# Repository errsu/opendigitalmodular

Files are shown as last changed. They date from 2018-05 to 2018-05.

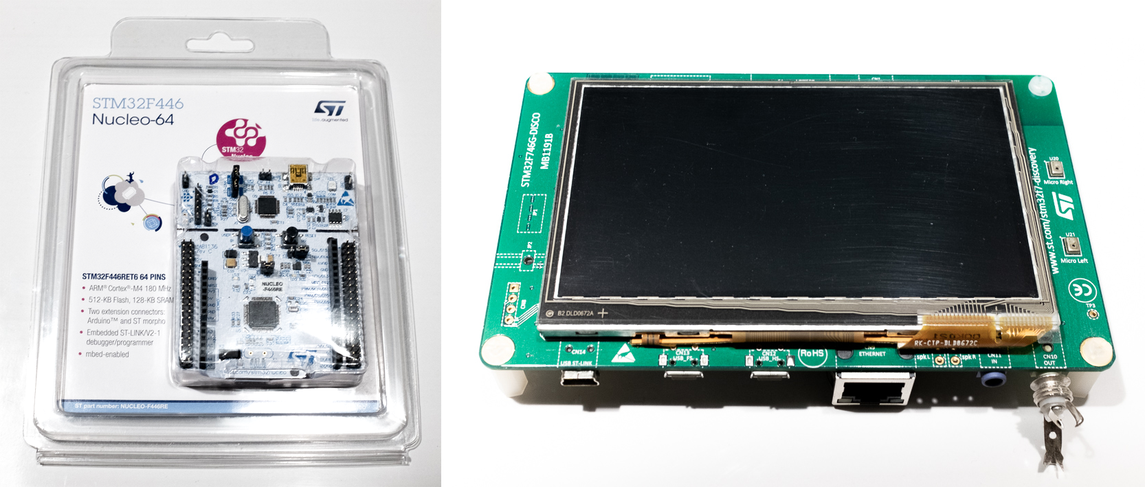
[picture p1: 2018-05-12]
documentation/images/stm32f_evaluation_boards.png

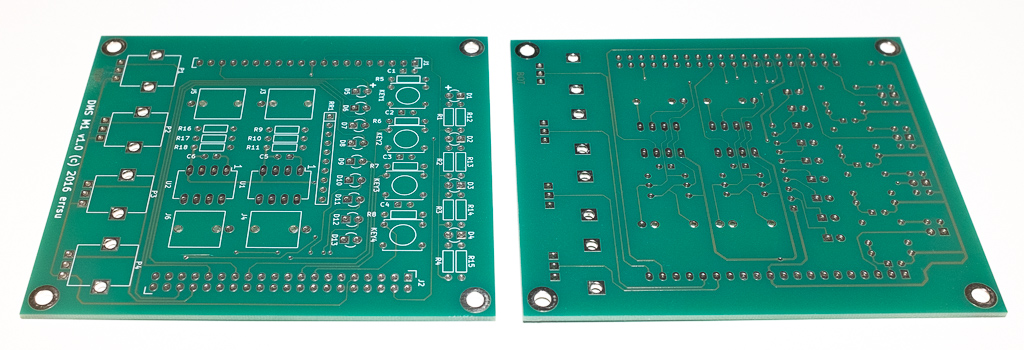
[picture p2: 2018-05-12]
documentation/images/odm_m1_pcb.png

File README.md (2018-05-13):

Open Digital Modular (ODM): Proposal for a Synthesizer Architecture
===================================================================

## What is it?

ODM is an architectural idea that is to be turned into a specification and
a prototype implementation. All this is work in progress. The details can
be found in the [ODM specification document](documentation/ODMSpecification.asc).

## License

See the [licenses page](LICENSES.asc) for details.

## Questions and comments

The main goal of making this public is to get in contact with people for review,
comments, proposals, criticism or laughter. Most valued would be cooperation, and
there is some hope that in the not-so-far future somebody might want to build
actual synthesizers this way.

So, please use the [issue page](https://github.com/errsu/opendigitalmodular/issues)
for public communication or send me a mail for a private conversation.

/errsu

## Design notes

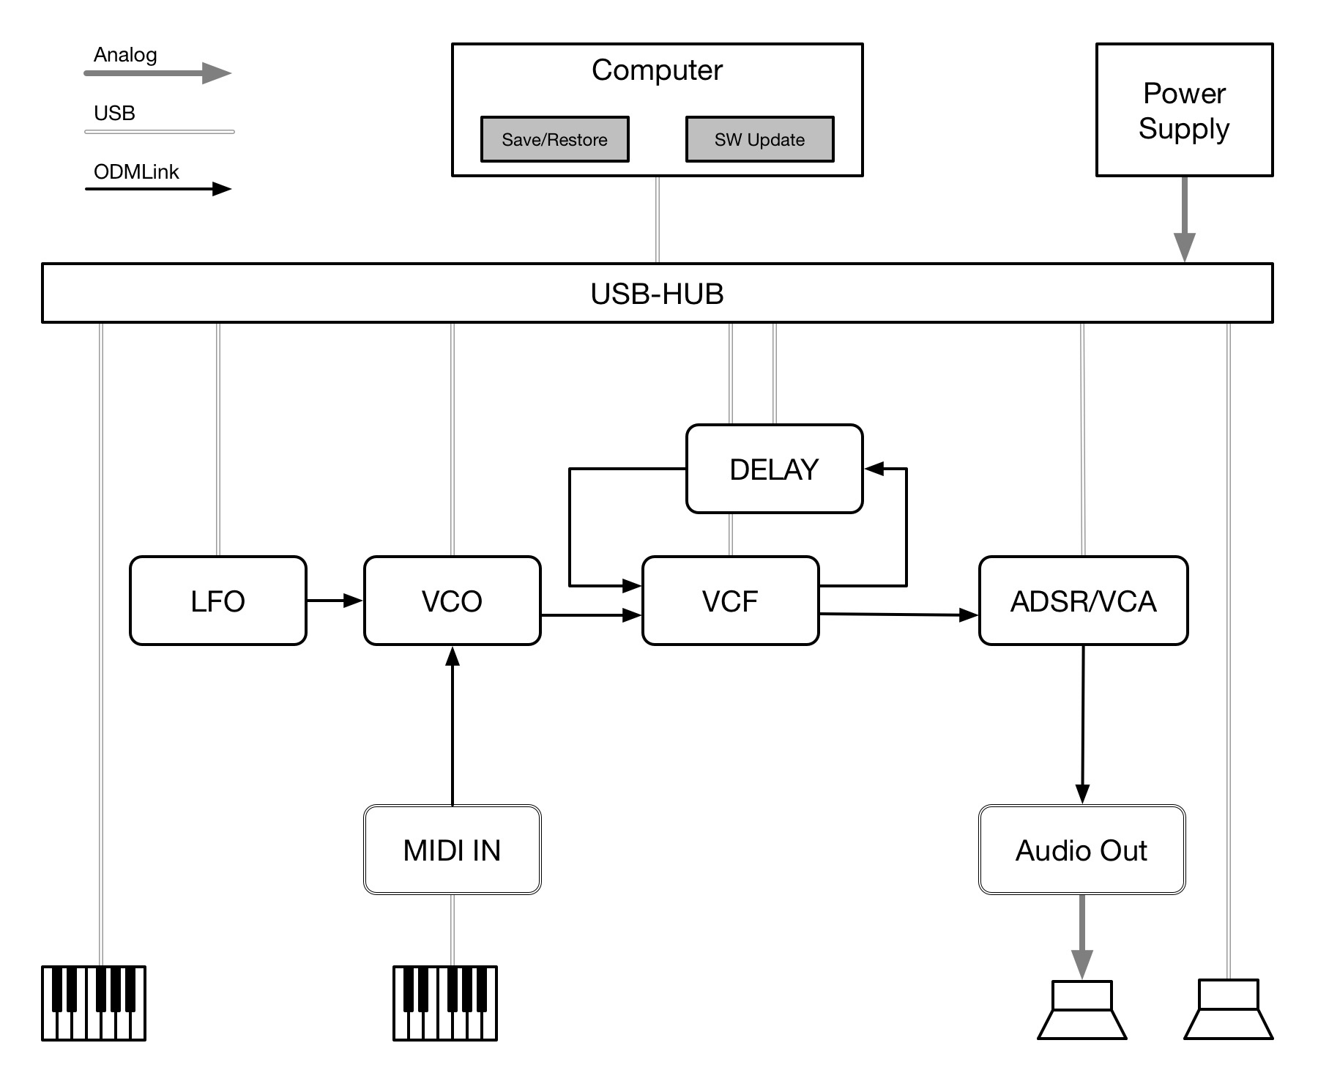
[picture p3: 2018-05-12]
documentation/images/architecture_overview.png

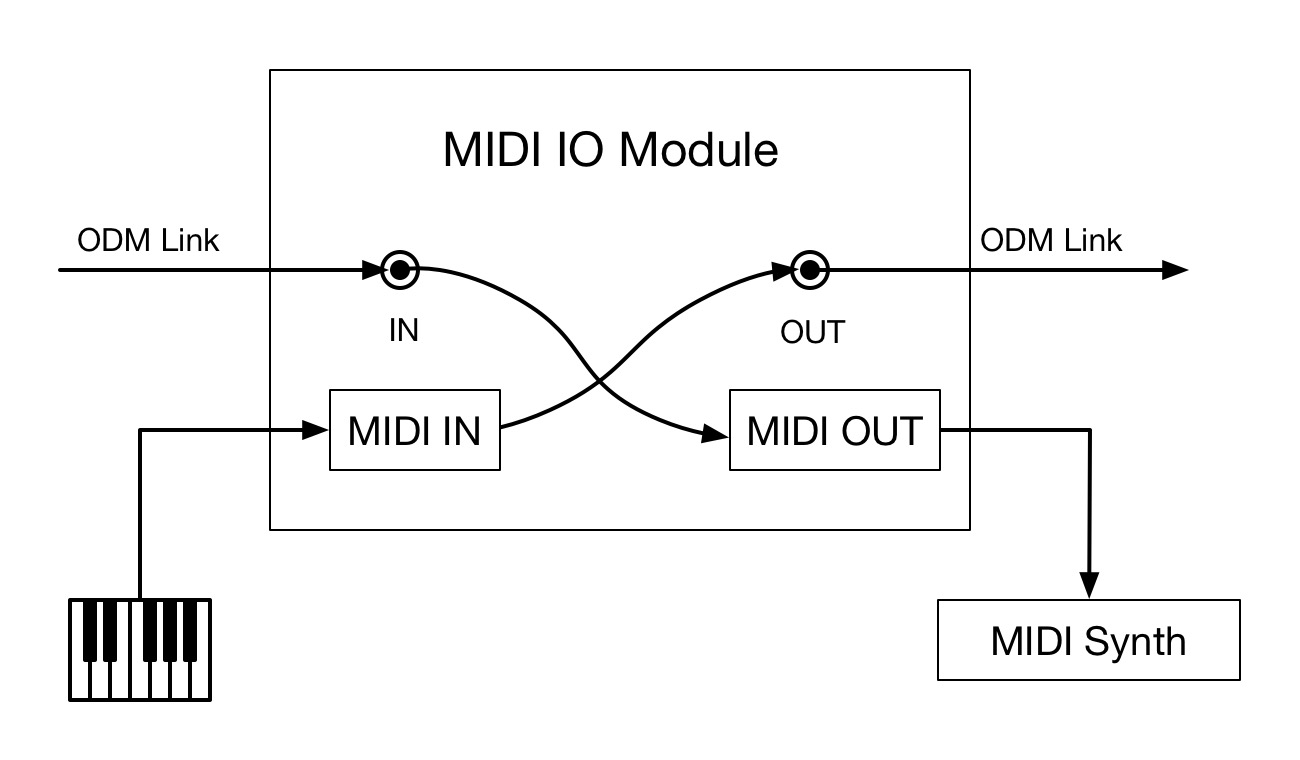
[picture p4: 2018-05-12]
documentation/images/direct_midi_io.png

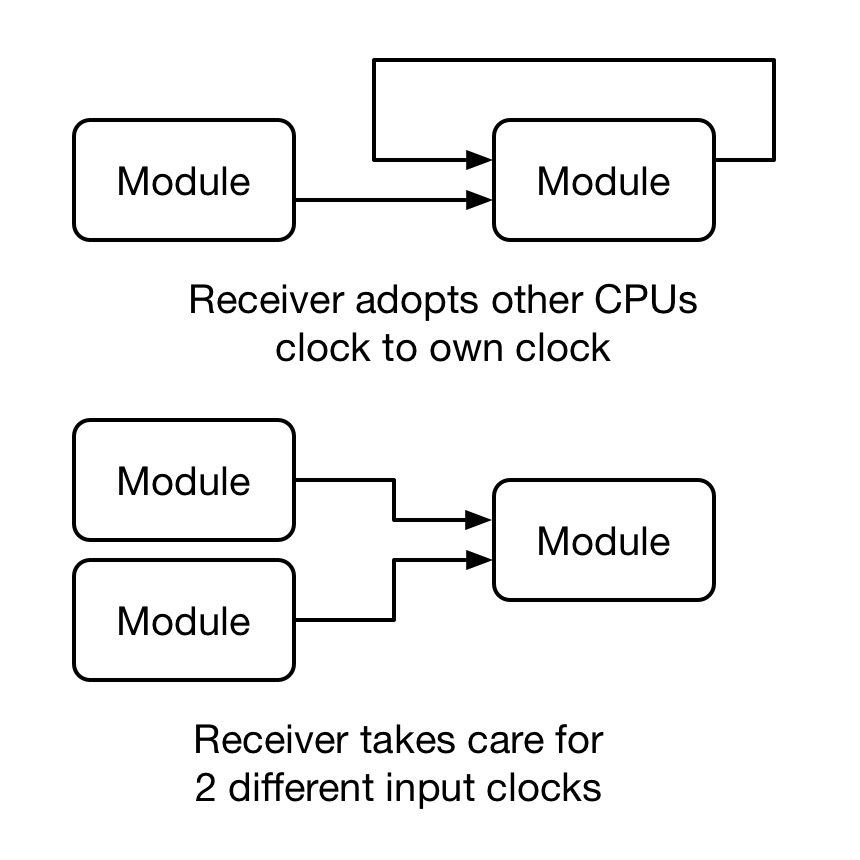
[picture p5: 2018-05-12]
documentation/images/sample_clock_sync.png

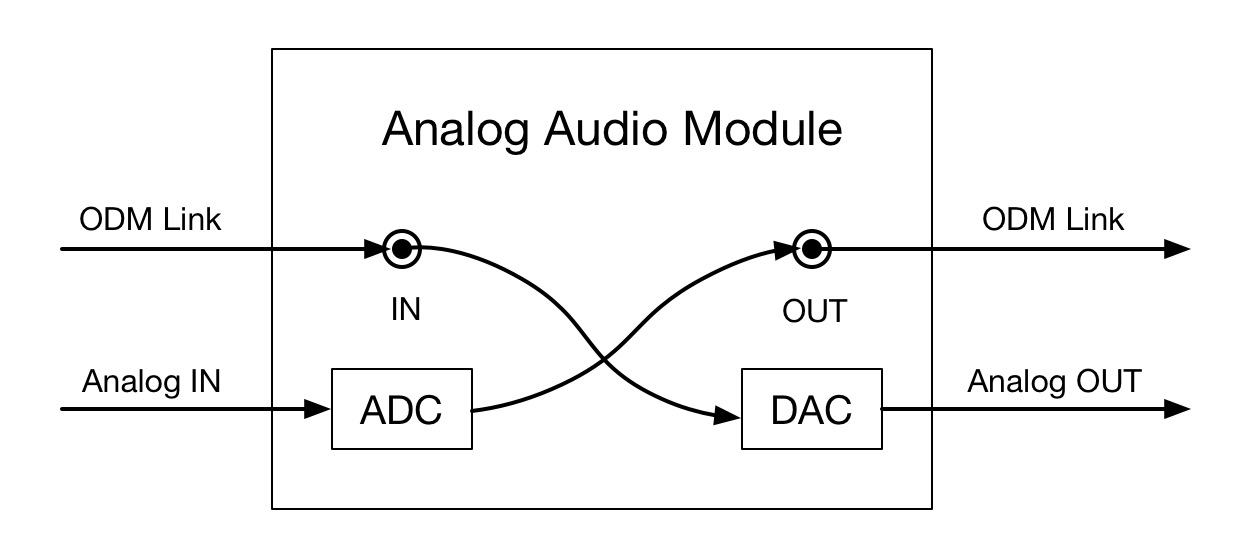
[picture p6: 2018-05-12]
documentation/images/direct_audio_io.png

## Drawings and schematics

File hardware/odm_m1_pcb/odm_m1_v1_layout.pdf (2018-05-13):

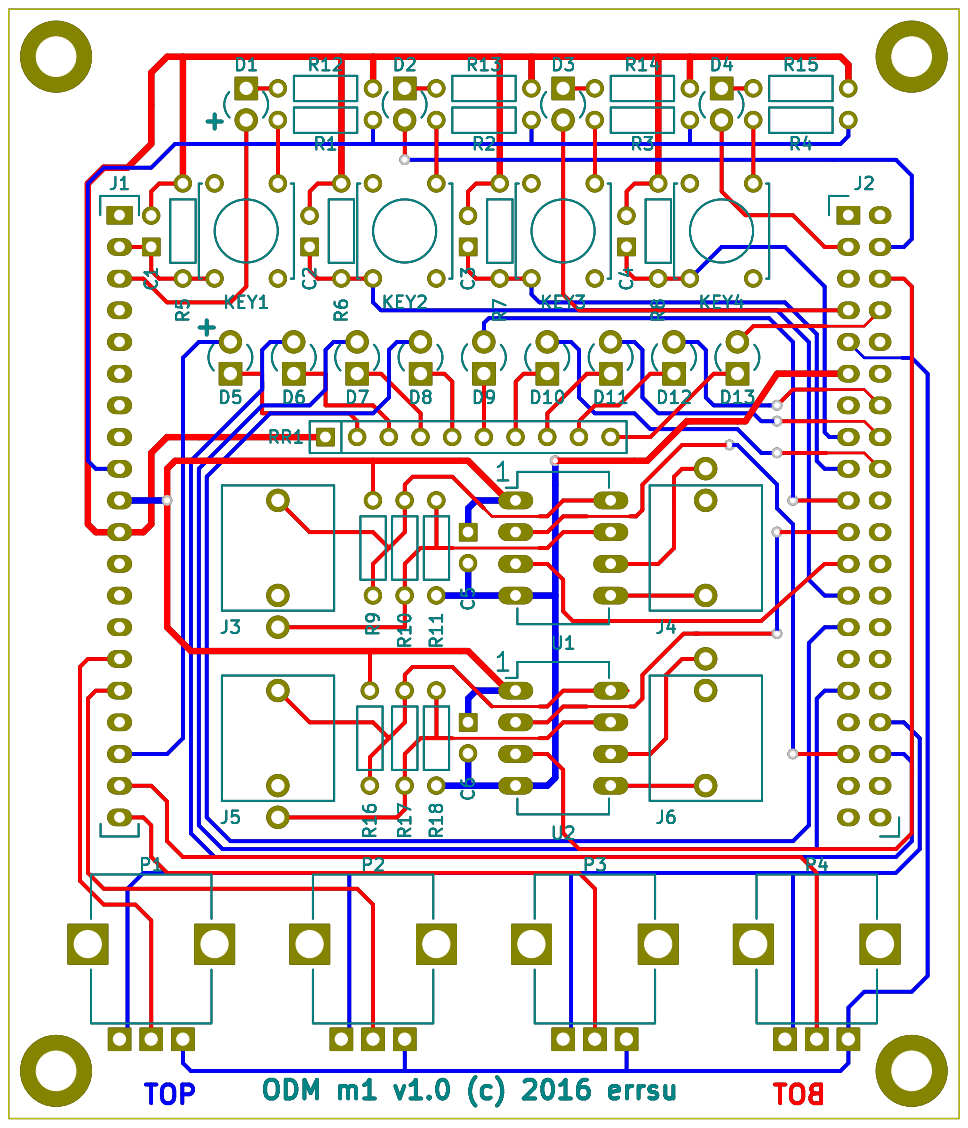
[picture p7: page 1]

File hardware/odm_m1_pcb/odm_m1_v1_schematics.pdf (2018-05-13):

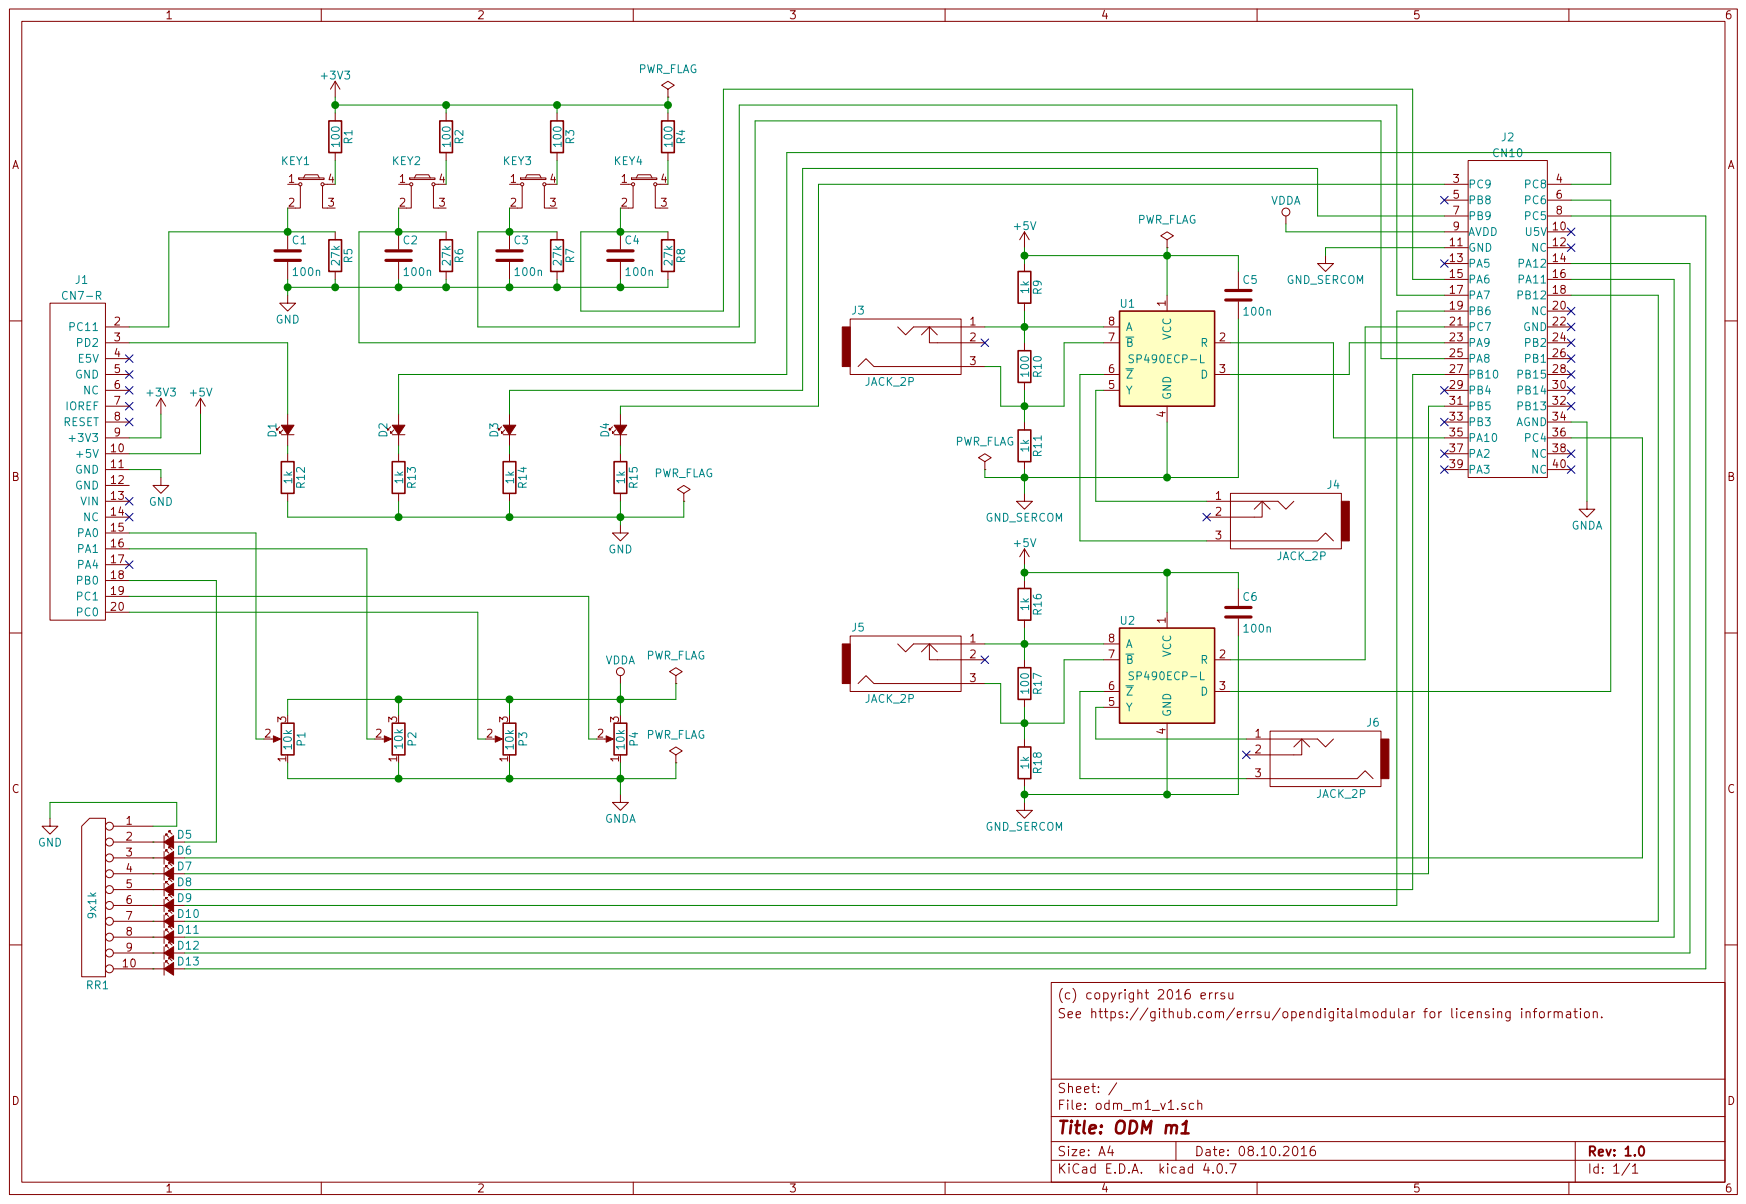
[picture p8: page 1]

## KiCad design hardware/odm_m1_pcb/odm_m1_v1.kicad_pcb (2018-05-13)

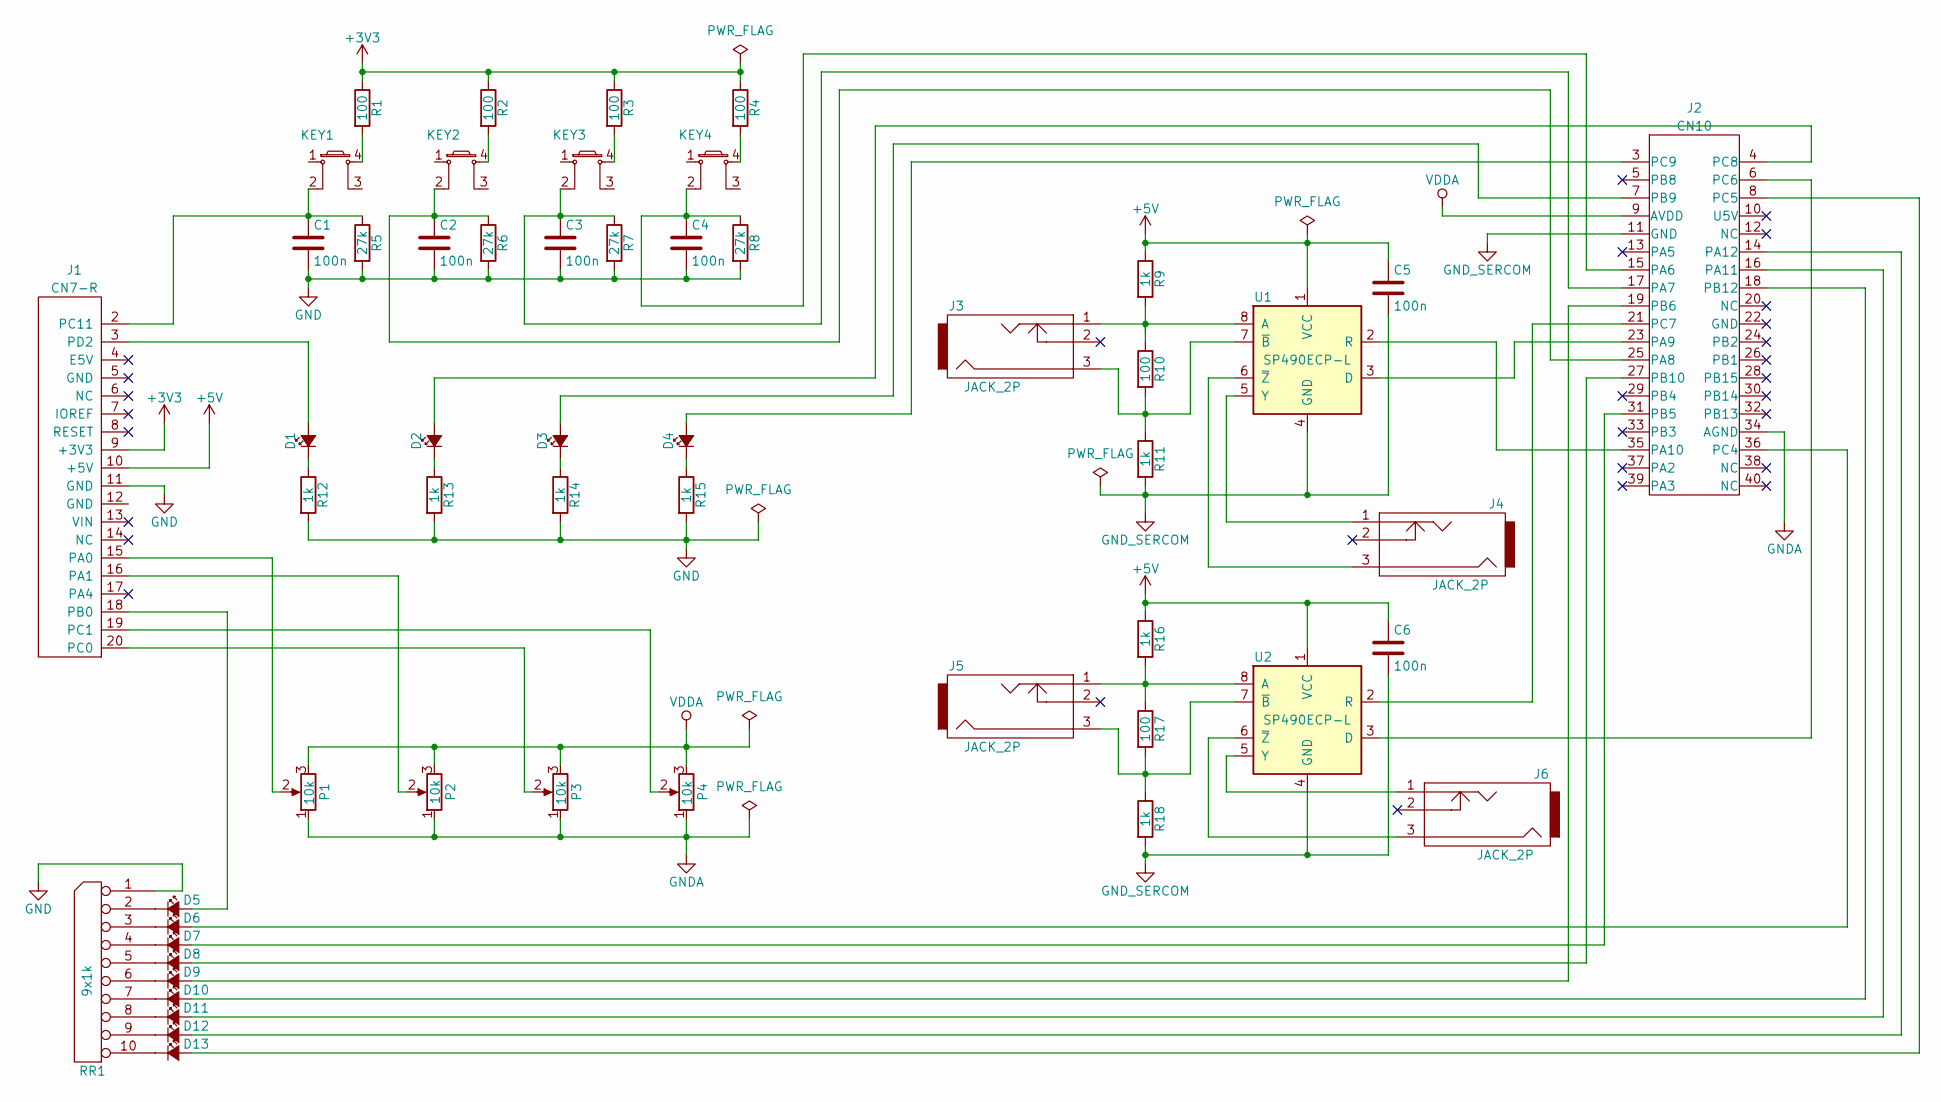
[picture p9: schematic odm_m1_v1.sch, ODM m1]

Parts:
C1, C2, C3, C4, C5, C6: 100n; C_Disc_D3_P2.5
D1, D2, D3, D4, D5, D6, D7, D8, D9, D10, D11, D12, D13: Led_Small; LED-3MM
J1: CN7-R; Socket_Strip_Straight_1x20_RS
J2: CN10; Socket_Strip_Straight_2x20_RS
J3, J4, J5, J6: JACK_2P; PHONEJACK_35MM_MONO_VERT
KEY1, KEY2, KEY3, KEY4: SW_PUSH; SW_PUSH_SMALL
P1, P2, P3, P4: 10k; POT_RK09
R1, R2, R3, R4, R10, R17: 100; Resistor_Horizontal_RM7mm
R5, R6, R7, R8: 27k; Resistor_Horizontal_RM7mm
R9, R11, R12, R13, R14, R15, R16, R18: 1k; Resistor_Horizontal_RM7mm
RR1: 9x1k; Resistor_Array_SIP9
U1, U2: SP490ECP-L; DIP-8_W7.62mm

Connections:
+3V3: J1.9 (+3V3), R1.1, R2.1, R3.1, R4.1
+5V: C5.1, C6.1, J1.10 (+5V), R9.1, R16.1, U1.1 (VCC), U2.1 (VCC)
GND: C1.2, C2.2, C3.2, C4.2, J1.11 (GND), R5.2, R6.2, R7.2, R8.2, R12.2, R13.2, R14.2, R15.2, RR1.1 (COM)
GNDA: J2.34 (AGND), P1.1, P2.1, P3.1, P4.1
GND_SERCOM: C5.2, C6.2, J2.11 (GND), R11.2, R18.2, U1.4 (GND), U2.4 (GND)
unnamed: C1.1, J1.2 (PC11), KEY1.2, R5.1
unnamed: C2.1, J2.25 (PA8), KEY2.2, R6.1
unnamed: C3.1, J2.17 (PA7), KEY3.2, R7.1
unnamed: C4.1, J2.15 (PA6), KEY4.2, R8.1
unnamed: D1.1 (K), R12.1
unnamed: D1.2 (A), J1.3 (PD2)
unnamed: D2.1 (K), R13.1
unnamed: D2.2 (A), J2.4 (PC8)
unnamed: D3.1 (K), R14.1
unnamed: D3.2 (A), J2.7 (PB9)
unnamed: D4.1 (K), R15.1
unnamed: D4.2 (A), J2.3 (PC9)
unnamed: D5.1 (K), RR1.2
unnamed: D5.2 (A), J1.18 (PB0)
unnamed: D6.1 (K), RR1.3
unnamed: D6.2 (A), J2.36 (PC4)
unnamed: D7.1 (K), RR1.4
unnamed: D7.2 (A), J2.31 (PB5)
unnamed: D8.1 (K), RR1.5
unnamed: D8.2 (A), J2.27 (PB10)
unnamed: D9.1 (K), RR1.6
unnamed: D9.2 (A), J2.19 (PB6)
unnamed: D10.1 (K), RR1.7
unnamed: D10.2 (A), J2.18 (PB12)
unnamed: D11.1 (K), RR1.8
unnamed: D11.2 (A), J2.16 (PA11)
unnamed: D12.1 (K), RR1.9
unnamed: D12.2 (A), J2.14 (PA12)
unnamed: D13.1 (K), RR1.10
unnamed: D13.2 (A), J2.8 (PC5)
unnamed: J1.15 (PA0), P1.2
unnamed: J1.16 (PA1), P2.2
unnamed: J1.19 (PC1), P4.2
unnamed: J1.20 (PC0), P3.2
unnamed: J2.6 (PC6), U2.3 (D)
unnamed: J2.21 (PC7), U2.2 (R)
unnamed: J2.23 (PA9), U1.3 (D)
unnamed: J2.35 (PA10), U1.2 (R)
unnamed: J3.1, R9.2, R10.1, U1.8 (A)
unnamed: J3.3, R10.2, R11.1, U1.7 (~B~)
unnamed: J4.1, U1.5 (Y)
unnamed: J4.3, U1.6 (~Z~)
unnamed: J5.1, R16.2, R17.1, U2.8 (A)
unnamed: J5.3, R17.2, R18.1, U2.7 (~B~)
unnamed: J6.1, U2.5 (Y)
unnamed: J6.3, U2.6 (~Z~)
unnamed: KEY1.4, R1.2
unnamed: KEY2.4, R2.2
unnamed: KEY3.4, R3.2
unnamed: KEY4.4, R4.2
VDDA: J2.9 (AVDD), P1.3, P2.3, P3.3, P4.3

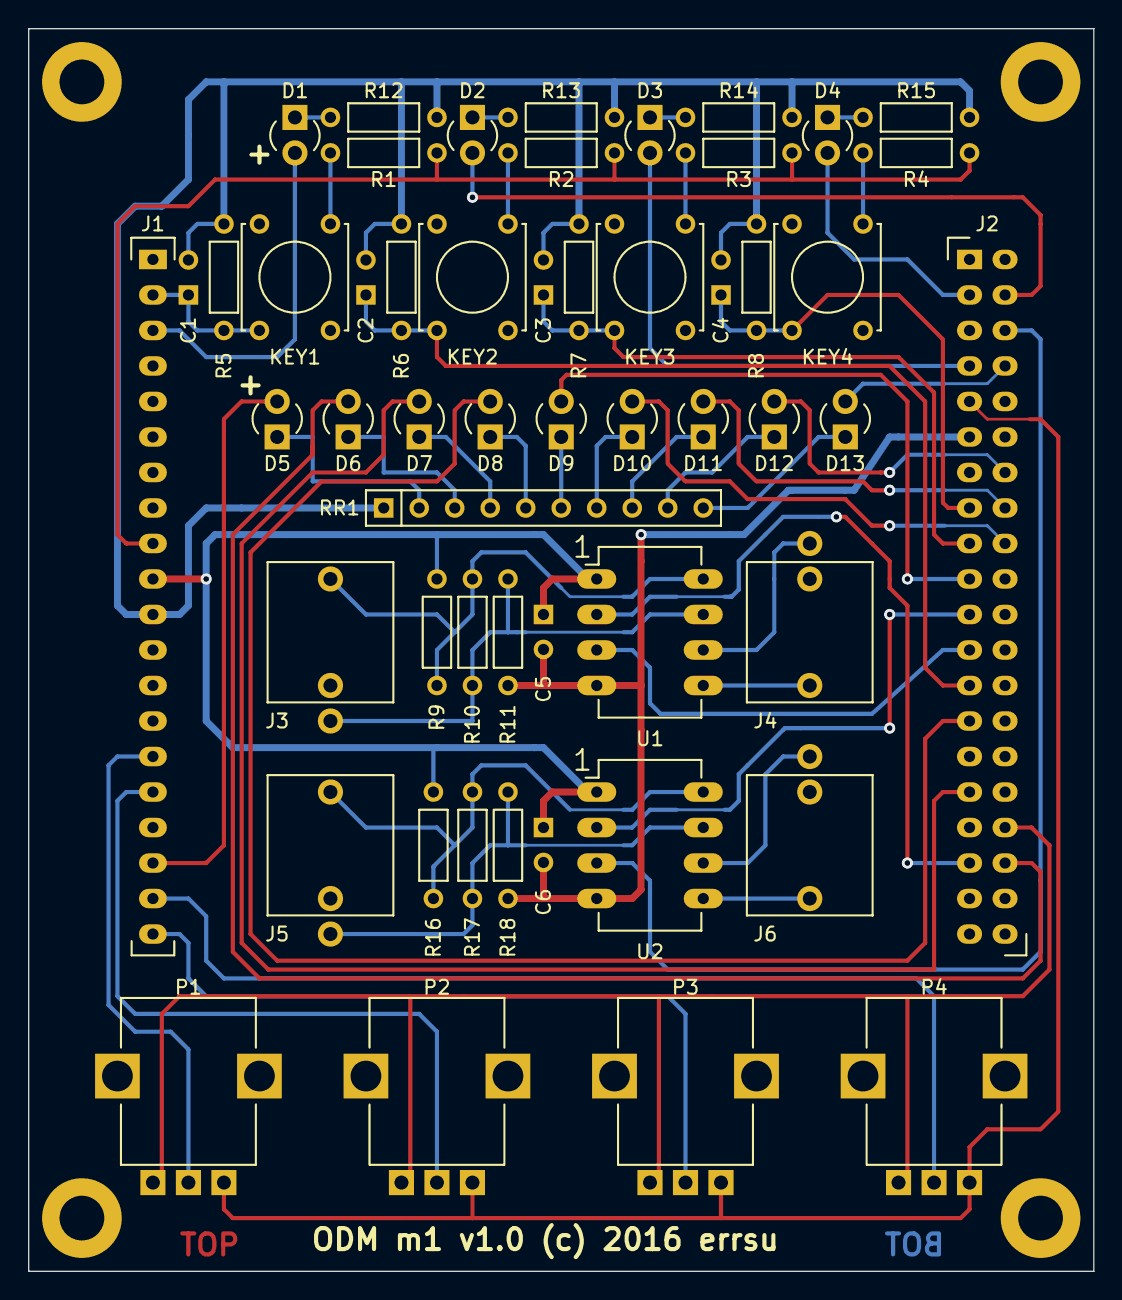
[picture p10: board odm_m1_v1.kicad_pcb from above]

Board: 2 copper layers, 76.2 x 88.9 mm, 54 parts (0 on the bottom side), 56 nets.

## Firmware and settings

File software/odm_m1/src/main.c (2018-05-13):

// (C) Copyright 2015-2018 Errsu
//
// Licensed under the Apache License, Version 2.0 (the "License");
// you may not use this file except in compliance with the License.
// You may obtain a copy of the License at
//
//    http://www.apache.org/licenses/LICENSE-2.0
//
// Unless required by applicable law or agreed to in writing, software
// distributed under the License is distributed on an "AS IS" BASIS,
// WITHOUT WARRANTIES OR CONDITIONS OF ANY KIND, either express or implied.
// See the License for the specific language governing permissions and
// limitations under the License.

#include "odm_adc.h"
#include "odm_clock.h"
#include "odm_dac.h"
#include "odm_gen.h"
#include "odm_gpio.h"
#include "odm_interrupts.h"
#include "odm_link.h"
#include "odm_misc.h"
#include "odm_printf.h"
#include "odm_timers.h"

#include "stm32f4xx.h"

#include <math.h>
#include <stdlib.h>
#include <stdio.h>

static float sin_gen_al_x;
static float sin_gen_al_delta;
static float sin_gen_ar_x;
static float sin_gen_ar_delta;
static float sin_gen_bl_x;
static float sin_gen_bl_delta;
static float sin_gen_br_x;
static float sin_gen_br_delta;

static float sin_gen_f1_x;
static float sin_gen_f1_delta;
static float sin_gen_f2_x;
static float sin_gen_f2_delta;

static float imp_gen_x;
static float imp_gen_delta;

static float envelope_gen_x;

static float al_in = 0.0;
static float ar_in = 0.0;
static float bl_in = 0.0;
static float br_in = 0.0;

static float al_out = 0.0;
static float ar_out = 0.0;
static float bl_out = 0.0;
static float br_out = 0.0;

static float freq_a = 50.0f;
static float dir_a  = 1.005f;
static float freq_b = 1000.0f;


static void update_freq_a()
{
  freq_a *= dir_a;

  if (dir_a > 1.0f && freq_a > 20000.0f)
  {
    dir_a = 0.996f;
  }
  if (dir_a < 1.0f && freq_a < 50.0f)
  {
    dir_a = 1.005f;
  }
  sin_gen_al_delta = odm_gen_calc_delta(freq_a);
  sin_gen_ar_delta = odm_gen_calc_delta(freq_a);
}

static void update_freq_b()
{
  freq_b += 1000.0f;
  if (freq_b > 20000.0f)
  {
    freq_b = 1000.0f;
  }
  sin_gen_bl_delta = odm_gen_calc_delta(freq_b);
  sin_gen_br_delta = odm_gen_calc_delta(freq_b);
}

void init_board1()
{
  sin_gen_al_x = 0.0f;
  sin_gen_ar_x = 0.0f;
  update_freq_a();
  sin_gen_bl_x = 0.0f;
  sin_gen_br_x = 0.0f;
  update_freq_b();

  imp_gen_x = 0.0f;
  imp_gen_delta = odm_gen_calc_delta(9600.0f);

  sin_gen_f1_x = 0.0f;
  sin_gen_f1_delta = odm_gen_calc_delta(300.0f);

  envelope_gen_x = 0.0f;

  odm_link_configure(&ODM_LINK_A);
  odm_link_configure(&ODM_LINK_B);
}

static uint8_t tx_sample_count = 0;
static uint32_t count_rect = 0;

void timer_callback_96000kHz_board1_signals()
{
  odm_link_send_frame(&ODM_LINK_A, tx_sample_count, al_out, ar_out);
  odm_link_send_frame(&ODM_LINK_B, tx_sample_count, bl_out, br_out);
  tx_sample_count++;

  odm_link_receive_audio(&ODM_LINK_A, &al_in, &ar_in);
  odm_link_receive_audio(&ODM_LINK_B, &bl_in, &br_in);

  al_out = odm_gen_sin_next(&sin_gen_al_x, sin_gen_al_delta);
  ar_out = odm_gen_sin_next(&sin_gen_ar_x, sin_gen_ar_delta);
  // bl_out = odm_gen_sin_next(&sin_gen_bl_x, sin_gen_bl_delta);
  // br_out = odm_gen_sin_next(&sin_gen_br_x, sin_gen_br_delta);
  // bl_out = br_out = odm_gen_impulse_next(&imp_gen_x, imp_gen_delta);
  // bl_out = br_out = odm_gen_rect_next(&imp_gen_x, imp_gen_delta);

  bl_out = br_out = (count_rect < 3) ? 1.0f : -1.0f;

  count_rect++;
  if (count_rect == 6)
  {
    count_rect = 0;
  }
}

void timer_callback_96000kHz_board1_hops()
{
  odm_link_send_frame(&ODM_LINK_A, tx_sample_count, al_out, ar_out);
  odm_link_send_frame(&ODM_LINK_B, tx_sample_count, bl_out, br_out);
  tx_sample_count++;

  odm_link_receive_audio(&ODM_LINK_A, &al_in, &ar_in);
  odm_link_receive_audio(&ODM_LINK_B, &bl_in, &br_in);

  ar_out = ar_in;
  al_out = al_in;
  br_out = br_in;
  bl_out = bl_in;
}

void timer_callback_96000kHz_board1_mix()
{
  odm_link_send_frame(&ODM_LINK_A, tx_sample_count, al_out, ar_out);
  tx_sample_count++;

  odm_link_receive_audio(&ODM_LINK_A, &al_in, &ar_in);

  float f1 = odm_gen_sin_next(&sin_gen_f1_x, sin_gen_f1_delta);
  float env = odm_gen_envelope(&envelope_gen_x);

  ar_out = (ar_in + f1 * env) * 0.9f;
  al_out = (al_in + f1) * 0.5f;
}

void timer_callback_96000kHz_board1_rs485()
{
  ODM_GPIO_PB8_TOGGLE();
  odm_link_send_frame(&ODM_LINK_A, 0xa5, -5.674839e12f, 0.0f);
}

void init_board2()
{
  sin_gen_f1_x = 0.0f;
  sin_gen_f1_delta = odm_gen_calc_delta(300.0f);

  sin_gen_f2_x = 0.0f;
  sin_gen_f2_delta = odm_gen_calc_delta(301.0f);

  odm_link_configure(&ODM_LINK_A);
  odm_link_configure(&ODM_LINK_B);
}

static uint8_t data_buffer[8];
static uint8_t last_data  = 0;

static int32_t stall_count = 0;
static int32_t jump_count = 0;

static int32_t message1 = 0;

void timer_callback_96000kHz_board2_signals()
{
  odm_link_send_frame(&ODM_LINK_A, 0, al_out, ar_out);
  odm_link_send_frame(&ODM_LINK_B, 0, bl_out, br_out);

  int32_t steps = odm_link_receive_audio(&ODM_LINK_A, &al_in, &ar_in);
  odm_link_receive_audio(&ODM_LINK_B, &bl_in, &br_in);

  if (steps == -1)
  {
    stall_count++;
  }
  if (steps == 2 || steps == 0)
  {
    jump_count++;
  }

  int32_t data_count = odm_link_receive_data(&ODM_LINK_A, data_buffer);
  for (int32_t i = 0; i < data_count; i++)
  {
    uint8_t data = data_buffer[i];
    if ((data & 0xFF) != ((last_data + 1) & 0xFF))
    {
      message1++;
    }
    last_data = data;
  }

  ODM_DAC_WRITE((uint32_t)((int)32768 + (int)(al_in * 16000.0f)),
                (uint32_t)((int)32768 + (int)(ar_in * 16000.0f)));
}

void timer_callback_96000kHz_board2_hops()
{
  odm_link_send_frame(&ODM_LINK_A, 0, al_out, ar_out);
  odm_link_send_frame(&ODM_LINK_B, 0, bl_out, br_out);

  odm_link_receive_audio(&ODM_LINK_A, &al_in, &ar_in);
  odm_link_receive_audio(&ODM_LINK_B, &bl_in, &br_in);

  float f1 = odm_gen_sin_next(&sin_gen_f1_x, sin_gen_f1_delta);

//  float f1 = (count_rect < 160) ? 1.0f : -1.0f;
//  count_rect++;
//  if (count_rect == 320)
//  {
//    count_rect = 0;
//  }

  // 7 hops
  ODM_DAC_WRITE((uint32_t)((int)32768 + (int)(bl_in * 16000.0f)),
                (uint32_t)((int)32768 + (int)(f1    * 16000.0f)));

  // 1 hop
  // ODM_DAC_WRITE((uint32_t)((int)32768 + (int)(ar_in * 16000.0f)),
  //               (uint32_t)((int)32768 + (int)(ref_sig * 16000.0f)));

  ar_out = f1;
  al_out = ar_in;
  br_out = al_in;
  bl_out = br_in;
}

#define DELAY_LEN 1024

static float delay_buffer[DELAY_LEN] = {0.0f, };
static uint32_t delay_head = 0;

void timer_callback_96000kHz_board2_mix()
{
  odm_link_send_frame(&ODM_LINK_A, 0, al_out, ar_out);

  odm_link_receive_audio(&ODM_LINK_A, &al_in, &ar_in);

  // right: 0.5*0.5 feedback output
  // left: sum of two sin gens from different CPUs
  float dac_r_out = ar_in * 0.5f;
  float dac_l_out = al_in;
  ODM_DAC_WRITE((uint32_t)((int)32768 + (int)(dac_r_out * 16000.0f)),
                (uint32_t)((int)32768 + (int)(dac_l_out * 16000.0f)));

  float f2 = odm_gen_sin_next(&sin_gen_f2_x, sin_gen_f2_delta);

  ar_out = delay_buffer[delay_head];
  delay_buffer[delay_head] = ar_in * 0.96f;
  delay_head = (delay_head + 1) % DELAY_LEN;

  al_out = f2;
}

void timer_callback_96000kHz_board2_rs485()
{
  uint8_t data[2];
  float left, right;

  int32_t step = odm_link_receive_audio(&ODM_LINK_A, &left, &right);
  odm_link_receive_data(&ODM_LINK_A, data);

  if (step < 0)
  {
    ODM_GPIO_PA0_OFF();
  }
  else
  {
    ODM_GPIO_PA0_ON();
  }

  if (data[0] == 0xa5 && left == -5.674839e12f && right == 0.0f)
  {
    ODM_GPIO_PC1_ON();
  }
  else
  {
    ODM_GPIO_PC1_OFF();
  }

  ODM_DAC_WRITE((uint32_t)((int)32768 + (int)(right * 16000.0f)),
                (uint32_t)((int)32768 + (int)(left  * 16000.0f)));
}

static void cpu_init()
{
  // enable instruction & data cache, prefetch buffer
  FLASH->ACR |= (FLASH_ACR_ICEN | FLASH_ACR_DCEN | FLASH_ACR_PRFTEN);
  NVIC_SetPriorityGrouping(ODM_INTERRUPT_PRIO_GROUPING);

  // enable FPU
  SCB->CPACR |= 0x00F00000; // addr = 0xE000ED88
  __DSB(); // data sync barrier
  __ISB(); // instruction sync barrier
}

int main(void)
{
  cpu_init();
  odm_clock_configure();
  odm_misc_init();

  odm_gpio_configure();
  odm_printf_configure();
  // odm_dac_configure();
  odm_adc_configure();

  printf("STM32F446 board %d\n", (int)odm_board_id());

  if (odm_board_id() == 0)
  {
    init_board1();
    odm_timers_configure(&timer_callback_96000kHz_board1_hops);
  }
  else if (odm_board_id() == 1)
  {
    init_board1();
    // odm_timers_configure(&timer_callback_96000kHz_board1_signals);
    // odm_timers_configure(&timer_callback_96000kHz_board1_hops);
    // odm_timers_configure(&timer_callback_96000kHz_board1_mix);
    // odm_timers_configure(&timer_callback_96000kHz_board1_rs485);
  }
  else if (odm_board_id() == 2)
  {
    init_board2();
    // odm_timers_configure(&timer_callback_96000kHz_board2_signals);
    // odm_timers_configure(&timer_callback_96000kHz_board2_hops);
    // odm_timers_configure(&timer_callback_96000kHz_board2_mix);
    // odm_timers_configure(&timer_callback_96000kHz_board2_rs485);
  }

  int count = 0;
//  int32_t last_stall_count = 0;
//  int32_t last_jump_count = 0;

  uint32_t last_adc_value[4] = {0, };
  uint32_t adc_num = 0;
  uint32_t adc_running = 0;

  for(;;)
  {
    update_freq_a();

    if (ODM_GPIO_KEY0_ISSET())
    {
      ODM_GPIO_LED0_ON();
    }
    else
    {
      ODM_GPIO_LED0_OFF() ;
    }

    if (ODM_GPIO_KEY1_ISSET())
    {
      ODM_GPIO_LED1_ON();
    }
    else
    {
      ODM_GPIO_LED1_OFF() ;
    }

    if (ODM_GPIO_KEY2_ISSET())
    {
      ODM_GPIO_LED2_ON();
    }
    else
    {
      ODM_GPIO_LED2_OFF() ;
    }

    if (ODM_GPIO_KEY3_ISSET())
    {
      ODM_GPIO_LED3_ON();
    }
    else
    {
      ODM_GPIO_LED3_OFF() ;
    }

//    if (count % 2048 == 0)
//    {
//      ODM_GPIO_LED3_OFF();
//      ODM_GPIO_LED0_ON();
//    }
//    else if (count % 2048 == 512)
//    {
//      ODM_GPIO_LED0_OFF();
//      ODM_GPIO_LED1_ON();
//    }
//    else if (count % 2048 == 1024)
//    {
//      ODM_GPIO_LED1_OFF();
//      ODM_GPIO_LED2_ON();
//    }
//    else if (count % 2048 == 1536)
//    {
//      ODM_GPIO_LED2_OFF();
//      ODM_GPIO_LED3_ON();
//    }
//
    if (count % 16 == 0)
    {
      if (!adc_running)
      {
        odm_adc_start(adc_num);
        adc_running = 1;
      }
      else
      {
        if (odm_adc_check())
        {
          uint32_t new_adc_value = odm_adc_get_result() / 16;
          if (new_adc_value != last_adc_value[adc_num])
          {
            last_adc_value[adc_num] = new_adc_value;
            printf("adc %03d %03d %03d %03d\n",
              (int)last_adc_value[0],
              (int)last_adc_value[1],
              (int)last_adc_value[2],
              (int)last_adc_value[3]);
          }
          adc_running = 0;
          adc_num = (adc_num + 1) % 4;
        }
      }
    }
    if (count++ == 4096)
    {
      update_freq_b();
      count = 0;
    }
//    if (last_stall_count != stall_count || last_jump_count != jump_count)
//    {
//      printf("s %d j %d\n", (int)stall_count, (int)jump_count);
//      last_stall_count = stall_count;
//      last_jump_count = jump_count;
//    }
//    if (message1 != 0)
//    {
//      printf("d %d\n", (int)message1);
//      message1 = 0;
//    }
    odm_clock_sleep(1);
  }
  exit(0);
}

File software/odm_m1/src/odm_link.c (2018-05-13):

// (C) Copyright 2015-2018 Errsu
//
// Licensed under the Apache License, Version 2.0 (the "License");
// you may not use this file except in compliance with the License.
// You may obtain a copy of the License at
//
//    http://www.apache.org/licenses/LICENSE-2.0
//
// Unless required by applicable law or agreed to in writing, software
// distributed under the License is distributed on an "AS IS" BASIS,
// WITHOUT WARRANTIES OR CONDITIONS OF ANY KIND, either express or implied.
// See the License for the specific language governing permissions and
// limitations under the License.

#include "odm_gpio.h"
#include "odm_interrupts.h"
#include "odm_link.h"
#include "odm_transrec.h"
#include "odm_timers.h"
#include "stm32f4xx.h"

#include <math.h>

#define ODM_LINK_FRAME_LENGTH 9
#define RX_DEBOUNCING 96*500 // 50 ms

//--------------------------------------------------------------------------------------
// TX: PA9 aka. D8, CN10.pin21   RX: PA10 aka. D2, CN10.pin33

odm_link_trx_t ODM_LINK_A =
{
  .port             = 0,
  .gpio_io          = GPIOA,
  .gpio_rx_pin      = 10,
  .gpio_rx_af       = 7,
  .gpio_tx_pin      = 9,
  .gpio_tx_af       = 7,

  .usart_io         = USART1,
  .usart_irqn       = USART1_IRQn,

  .dma_tx_stream_io = DMA2_Stream7,
  .dma_tx_channel   = 4,
  .dma_tx_ifcr      = &(DMA2->HIFCR),
  .dma_tx_ifcm      = DMA_HISR_TCIF7,

  .dma_rx_stream_io = DMA2_Stream2,
  .dma_rx_channel   = 4,
  .dma_rx_isr       = &(DMA2->LISR),
  .dma_rx_ifcr      = &(DMA2->LIFCR),
  .dma_rx_ifm       = DMA_LISR_FEIF2
                    | DMA_LISR_DMEIF2
                    | DMA_LISR_TEIF2
                    | DMA_LISR_HTIF2
                    | DMA_LISR_TCIF2,
  .dma_rx_irqn      = DMA2_Stream2_IRQn,
};

//--------------------------------------------------------------------------------------
// TX: PC6, CN10.pin4    RX: PC7 aka. D9, CN10.pin19

odm_link_trx_t ODM_LINK_B =
{
  .port             = 1,
  .gpio_io          = GPIOC,
  .gpio_rx_pin      = 7,
  .gpio_rx_af       = 8,
  .gpio_tx_pin      = 6,
  .gpio_tx_af       = 8,

  .usart_io         = USART6,
  .usart_irqn       = USART6_IRQn,

  .dma_tx_stream_io = DMA2_Stream6,
  .dma_tx_channel   = 5,
  .dma_tx_ifcr      = &(DMA2->HIFCR),
  .dma_tx_ifcm      = DMA_HISR_TCIF6,

  .dma_rx_stream_io = DMA2_Stream1,
  .dma_rx_channel   = 5,
  .dma_rx_isr       = &(DMA2->LISR),
  .dma_rx_ifcr      = &(DMA2->LIFCR),

  .dma_rx_ifm       = DMA_LISR_FEIF1
                    | DMA_LISR_DMEIF1
                    | DMA_LISR_TEIF1
                    | DMA_LISR_HTIF1
                    | DMA_LISR_TCIF1,
  .dma_rx_irqn      = DMA2_Stream1_IRQn,
};

//--------------------------------------------------------------------------------------

static void stop_rx_dma(odm_link_trx_t* htrx)
{
  // disable DMA stream
  htrx->dma_rx_stream_io->CR &= ~DMA_SxCR_EN;
  while (htrx->dma_rx_stream_io->CR & DMA_SxCR_EN)
  {
  }

  *htrx->dma_rx_ifcr = htrx->dma_rx_ifm;

  htrx->rx_receiving = 0;
  htrx->rx_data_read_head = 0;
  htrx->rx_audio_read_head = 0;

  htrx->dma_rx_stream_io->CR &= (~DMA_SxCR_CT);
  htrx->dma_rx_stream_io->NDTR = ODM_LINK_FRAME_LENGTH;
  htrx->dma_rx_stream_io->M0AR = (uint32_t)(&htrx->rx_buffer[0]);
  htrx->dma_rx_stream_io->M1AR = (uint32_t)(&htrx->rx_buffer[1]);

  // underflow values (in "previous" buffer)
  htrx->rx_buffer[3].left  = 0.0;
  htrx->rx_buffer[3].right = 0.0;
  htrx->rx_buffer[3].data  = 0;
}

static uint32_t read_usart_sr_drop_dr(odm_link_trx_t* htrx)
{
  __IO uint32_t sr, dummy_dr;
  sr       = htrx->usart_io->SR;
  dummy_dr = htrx->usart_io->DR;
  (void)dummy_dr;
  (void)sr;
  return sr;
}

static void start_rx_dma(odm_link_trx_t* htrx)
{
  htrx->dma_rx_stream_io->CR |= DMA_SxCR_EN; // enable DMA
}

#if 0
static void print_usart_interrupt_state(odm_link_trx_t* htrx, uint32_t sr)
{
  printf("%d) S: %d IE:", (int)htrx->port, (int)htrx->rx_state);

  uint32_t cr1 = htrx->usart_io->CR1;
  uint32_t cr3 = htrx->usart_io->CR3;

  if (cr1 & USART_CR1_UE)     { printf(" UE");   }
  if (cr1 & USART_CR1_RXNEIE) { printf(" RXNE"); }
  if (cr1 & USART_CR1_IDLEIE) { printf(" IDLE"); }
  if (cr1 & USART_CR1_RWU)    { printf(" RWU");  }
  if (cr3 & USART_CR3_DMAR)   { printf(" DMAR"); }
  if (cr3 & USART_CR3_EIE)    { printf(" EIE");  }

  printf(" -- SET:");

  if (sr & USART_SR_CTS)  { printf(" CTS");  }
  if (sr & USART_SR_LBD)  { printf(" LBD");  }
  if (sr & USART_SR_TXE)  { printf(" TXE");  }
  if (sr & USART_SR_TC)   { printf(" TC");   }
  if (sr & USART_SR_RXNE) { printf(" RXNE"); }
  if (sr & USART_SR_IDLE) { printf(" IDLE"); }
  if (sr & USART_SR_ORE)  { printf(" ORE");  }
  if (sr & USART_SR_NE)   { printf(" NE");   }
  if (sr & USART_SR_FE)   { printf(" FE");   }
  if (sr & USART_SR_PE)   { printf(" PE");   }

  printf("\n");
}
#endif

#if 0

static void print_dec(const char * text, uint32_t value)
{
  printf("%s   %08d\n", text, (int)value);
}

static void print_hex(const char * text, uint32_t value)
{
  printf("%s 0x%08x\n", text, (unsigned int)value);
}

static void print_state_a(const char* text)
{
  printf("%s\n\n", text);

  print_dec("PORT", ODM_LINK_A.port);
  print_dec("STAT", ODM_LINK_A.rx_state);
  print_dec("DATA", ODM_LINK_A.rc_data_read_head);
  print_dec("AUDI", ODM_LINK_A.rc_audio_read_head);
  print_dec("RCNG", ODM_LINK_A.rx_receiving);

  print_hex("CR  ", ODM_LINK_A.dma_rx_stream_io->CR);
  print_dec("NTDR", ODM_LINK_A.dma_rx_stream_io->NDTR);
  print_hex("M0AR", ODM_LINK_A.dma_rx_stream_io->M0AR);
  print_hex("M1AR", ODM_LINK_A.dma_rx_stream_io->M1AR);
  print_hex("PAR ", ODM_LINK_A.dma_rx_stream_io->PAR);
  print_hex("FCR ", ODM_LINK_A.dma_rx_stream_io->FCR);
  print_hex("ISR",  *ODM_LINK_A.dma_rx_isr);

  print_hex("SR  ", ODM_LINK_A.usart_io->SR);
  print_dec("DR  ", ODM_LINK_A.usart_io->DR);
  print_hex("CR1 ", ODM_LINK_A.usart_io->CR1);
  print_hex("CR2 ", ODM_LINK_A.usart_io->CR2);
  print_hex("CR3 ", ODM_LINK_A.usart_io->CR3);
  print_hex("BRR ", ODM_LINK_A.usart_io->BRR);

  for(int i= 0; i < RXBUFSIZE; i++)
  {
    printf("BUF [%d] %f %f %d\n", i, (double)ODM_LINK_A.rx_buffer[i].left,
                                     (double)ODM_LINK_A.rx_buffer[i].right,
                                     (int)ODM_LINK_A.rx_buffer[i].data);
  }

  printf("\n");
}

#endif

//--------------------------------------------------------------------------------------
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

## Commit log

2018-05-11 add some prototype board images
2018-05-12 add the ODM m1 PCB prototype
    [odm_m1_v1.kicad_pcb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]
2018-05-13 add the ODM m1 prototype software

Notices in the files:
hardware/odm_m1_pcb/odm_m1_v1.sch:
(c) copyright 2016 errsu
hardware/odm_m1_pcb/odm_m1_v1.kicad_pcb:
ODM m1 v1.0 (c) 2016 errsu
